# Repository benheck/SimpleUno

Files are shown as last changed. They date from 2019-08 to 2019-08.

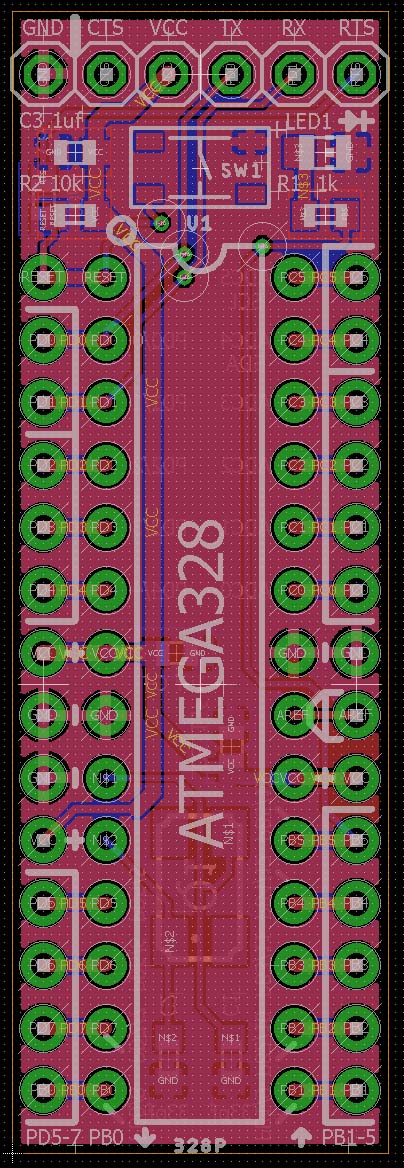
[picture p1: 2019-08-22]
top_solder.jpg

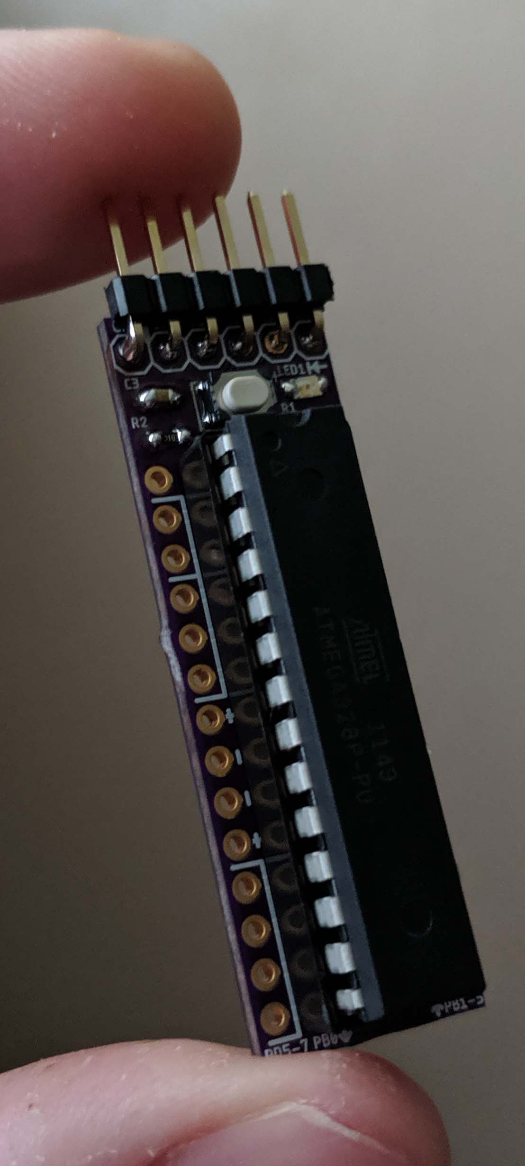
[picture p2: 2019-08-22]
mini uno held.jpg

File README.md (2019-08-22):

# SimpleUno
An extremely bare-bones ATMEGA328P PDIP-28 Arduino Uno compatible dev board.

INSTRUCTIONS:

Use existing socketed Arduino Uno dev board to flash bootloader/fuses onto a PDIP-28 ATMEG328P

Place programmed IC into this dev board either directly soldered or with a socket.

Attach 6 pin FTDI cable, breakout board or such compatible device.

In Arduino IDE select the FTDI's port and set the board as Arduino Uno.

Program away!

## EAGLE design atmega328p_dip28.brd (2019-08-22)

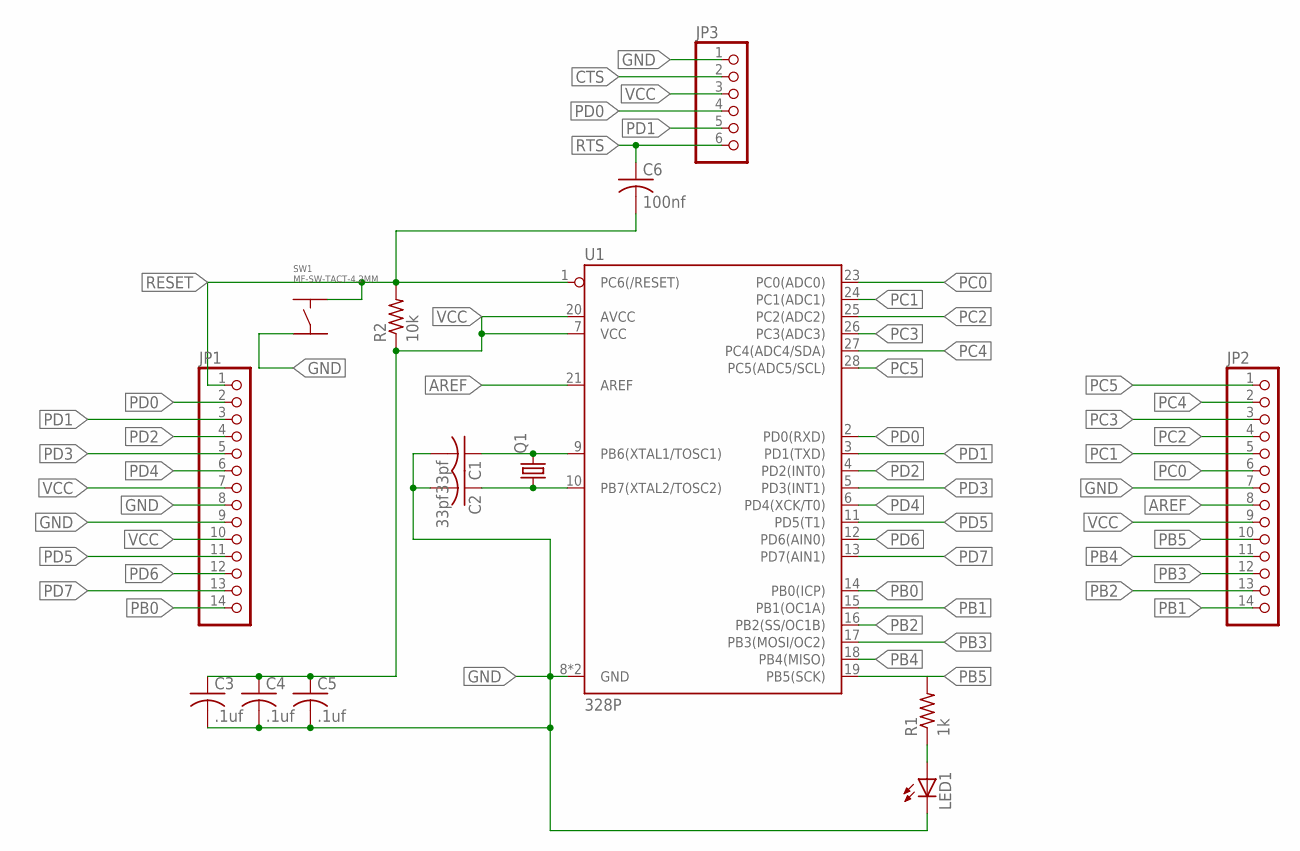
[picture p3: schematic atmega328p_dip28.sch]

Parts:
C1, C2: 33pf; C0603K
C3, C4, C5: .1uf; C0603
C6: 100nf; C0603
JP1, JP2: PINHD-1X14-CB; 1X14-CB
JP3: PINHD-1X6; 1X06
LED1: LEDCHIP-LED0805; CHIP-LED0805
Q1: CRYSTALCTS406; CTS406
R1: 1k; R0603
R2: 10k; R0603
SW1: MF-SW-TACT-4.2MM; MF_SWITCHES_TACT4.2MM
U1: 328P; DIP28

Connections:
AREF: JP2.8, U1.21 (AREF)
CTS: JP3.2
GND: C1.2, C2.2, C3.2, C4.2, C5.2, JP1.8, JP1.9, JP2.7, JP3.1, LED1.C, SW1.P$3, U1.8 (GND), U1.22 (GND)
unnamed: C1.1, Q1.3 (2), U1.9 (PB6(XTAL1/TOSC1))
unnamed: C2.1, Q1.1, U1.10 (PB7(XTAL2/TOSC2))
unnamed: LED1.A, R1.1
PB0: JP1.14, U1.14 (PB0(ICP))
PB1: JP2.14, U1.15 (PB1(OC1A))
PB2: JP2.13, U1.16 (PB2(SS/OC1B))
PB3: JP2.12, U1.17 (PB3(MOSI/OC2))
PB4: JP2.11, U1.18 (PB4(MISO))
PB5: JP2.10, R1.2, U1.19 (PB5(SCK))
PC0: JP2.6, U1.23 (PC0(ADC0))
PC1: JP2.5, U1.24 (PC1(ADC1))
PC2: JP2.4, U1.25 (PC2(ADC2))
PC3: JP2.3, U1.26 (PC3(ADC3))
PC4: JP2.2, U1.27 (PC4(ADC4/SDA))
PC5: JP2.1, U1.28 (PC5(ADC5/SCL))
PD0: JP1.2, JP3.4, U1.2 (PD0(RXD))
PD1: JP1.3, JP3.5, U1.3 (PD1(TXD))
PD2: JP1.4, U1.4 (PD2(INT0))
PD3: JP1.5, U1.5 (PD3(INT1))
PD4: JP1.6, U1.6 (PD4(XCK/T0))
PD5: JP1.11, U1.11 (PD5(T1))
PD6: JP1.12, U1.12 (PD6(AIN0))
PD7: JP1.13, U1.13 (PD7(AIN1))
RESET: C6.2, JP1.1, R2.2, SW1.P$2, U1.1 (PC6(/RESET))
RTS: C6.1, JP3.6
VCC: C3.1, C4.1, C5.1, JP1.7, JP1.10, JP2.9, JP3.3, R2.1, U1.7 (VCC), U1.20 (AVCC)

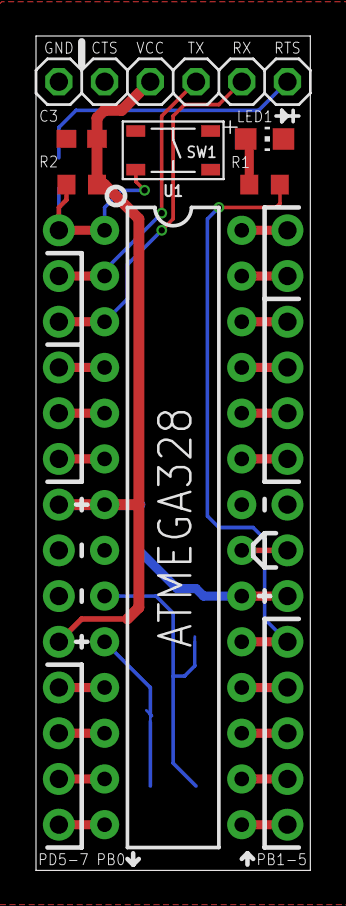
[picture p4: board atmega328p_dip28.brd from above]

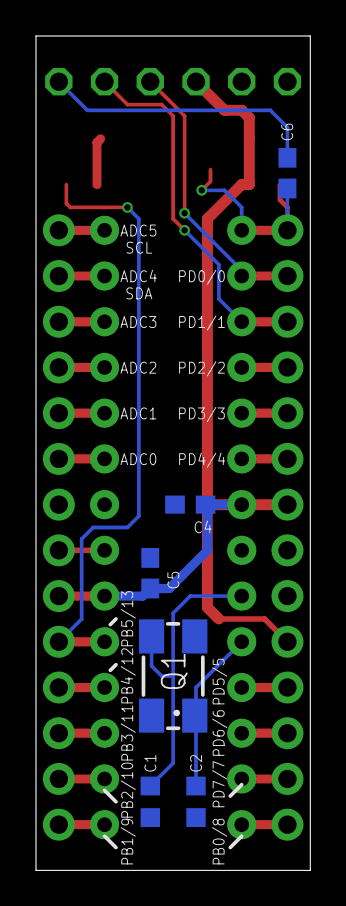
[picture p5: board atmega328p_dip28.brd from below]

Board: 2 copper layers, 15.2 x 46.4 mm, 15 parts (6 on the bottom side), 28 nets.

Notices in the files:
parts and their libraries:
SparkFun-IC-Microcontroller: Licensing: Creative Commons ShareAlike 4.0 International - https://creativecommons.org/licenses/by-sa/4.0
